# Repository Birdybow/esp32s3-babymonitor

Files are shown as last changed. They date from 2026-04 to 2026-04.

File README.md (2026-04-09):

# ESP32-S3 BabyMonitor

A self-hosted baby monitor built on the **Freenove ESP32-S3 WROOM (N16R8)** with full two-way communication — live video, live audio, and push-to-talk — all accessible from a web browser or Home Assistant dashboard.

No cloud. No app. No subscription.

---

## Features

- **Live video** — MJPEG stream over HTTP (port 80), compatible with go2rtc and Home Assistant
- **Live audio** — continuous WAV stream from INMP441 microphone (port 81)
- **Push-to-talk** — hold a button in the browser to speak through the MAX98357A speaker (port 82)
- **mDNS** — access via `http://babymonitor.local` without finding the IP address
- **Home Assistant integration** — embed video via go2rtc and the audio/talk player as dashboard cards

---

## Hardware

| Component | Part | Pins |
|---|---|---|
| Microcontroller | Freenove ESP32-S3 WROOM N16R8 | — |
| Camera | OV5640 (built-in) | XCLK=15, SIOD=4, SIOC=5, VSYNC=6, HREF=7, PCLK=13, Y2–Y9=11,9,8,10,12,18,17,16 |
| Microphone | INMP441 (I2S) | SCK=GPIO3, WS=GPIO21, SD=GPIO1 |
| Speaker amplifier | MAX98357A (I2S) | BCLK=GPIO41, LRC=GPIO42, DOUT=GPIO47 |

> **Note:** GPIO14 is defective (stuck HIGH) on the tested board. GPIO3 is used for I2S SCK instead — it is a strapping pin but works reliably as I2S clock after boot.

---

## Wiring

```
INMP441 microphone:
  VDD  → 3.3V
  GND  → GND
  SCK  → GPIO3
  WS   → GPIO21
  SD   → GPIO1
  L/R  → GND  (selects left channel)

MAX98357A speaker amplifier:
  VIN  → 5V
  GND  → GND
  BCLK → GPIO41
  LRC  → GPIO42
  DIN  → GPIO47
```

---

## HTTP Endpoints

| Port | Path | Description |
|---|---|---|
| 80 | `/` | Status page with links |
| 80 | `/stream` | MJPEG live video stream |
| 80 | `/capture` | Single JPEG snapshot |
| 81 | `/audio` | WAV audio stream (16kHz, 16-bit mono) |
| 82 | `/player` | Browser UI — listen + push-to-talk |
| 82 | `/speak` | POST endpoint — receives PCM audio, plays on speaker |

---

## Arduino IDE Setup

1. Install **ESP32 board support** (Espressif) in Arduino IDE
2. Select board: `ESP32S3 Dev Module`
3. Settings:
   - Flash: `16MB (128Mb)`
   - Partition Scheme: `Huge APP (3MB No OTA / 1MB SPIFFS)`
   - PSRAM: `OPI PSRAM`
   - USB CDC On Boot: `Disabled`
4. Open `firmware/BabyMonitor.ino`
5. Edit WiFi credentials at the top of the file:
   ```cpp
   static const char* WIFI_SSID = "DITT_WIFI_NAVN";
   static const char* WIFI_PASS = "DITT_WIFI_PASSORD";
   ```
6. Flash via the right USB-C port (CH343 UART)

---

## Browser – Push-to-Talk (getUserMedia over HTTP)

Chrome blocks microphone access on non-HTTPS origins by default. To allow it on your local network:

1. Open: `chrome://flags/#unsafely-treat-insecure-origin-as-secure`
2. Add: `http://babymonitor.local:82`
3. Click **Enable** → **Relaunch**
4. Go to `http://babymonitor.local:82/player`
5. Hold the blue button to speak

---

## Home Assistant Integration

### go2rtc (video)

Add to `/config/go2rtc.yaml`:
```yaml
streams:
  babymonitor_video:
    - ffmpeg:http://babymonitor.local/stream#video=mjpeg
```

### Dashboard cards

**Video card** (Webpage card):
```
http://<your-ha-ip>:11984/stream.html?src=babymonitor_video&mode=mjpeg
```

**Audio/talk card** (Webpage card):
```
http://babymonitor.local:82/player
```

---

## 3D Printed Enclosure

The `hardware/` folder contains a `.3mf` file (Bambu Lab format) for a wall-mounted enclosure designed around the SG90 servo pan mechanism.

**Design concept:** The SG90 servo is fixed to the wall. The bowl-shaped enclosure (containing the ESP32-S3, microphone, and speaker) rotates around the servo horn, giving 180° horizontal pan.

**Print settings used:**
| Setting | Value |
|---|---|
| Printer | Bambu Lab |
| Filament | PLA |
| Layer height | 0.2 mm |
| Infill | 15% |
| Supports | No |

**Assembly notes:**
- Glue the SG90 plastic horn wings to the bottom of the bowl
- Mount the servo body to the wall — the enclosure rotates around it
- Route cables (USB-C power, speaker wires) with enough slack for full 180° rotation
- SG90 requires a **separate 5V power supply** — the ESP32-S3 board's 5V pin only delivers ~4.1V which is insufficient

> The `.3mf` file opens in Bambu Studio and most modern slicers (PrusaSlicer, OrcaSlicer).

---

## Architecture

Three separate HTTP servers are required because `esp_http_server` is single-threaded. The MJPEG stream handler on port 80 holds the connection permanently — if `/player` were also on port 80, it would never receive a response.

```
Port 80  — video_server  — /stream (blocking MJPEG), /capture, /
Port 81  — audio_server  — /audio  (blocking WAV stream)
Port 82  — speak_server  — /player (HTML UI), /speak (POST PCM → speaker)
```

```mermaid
flowchart LR
    subgraph ESP32-S3
        CAM[OV5640\nCamera]
        MIC[INMP441\nMicrophone]
        SPK[MAX98357A\nSpeaker]
        P80[Port 80\nvideo_server]
        P81[Port 81\naudio_server]
        P82[Port 82\nspeak_server]
        CAM --> P80
        MIC --> P81
        P82 --> SPK
    end

    subgraph Home Assistant
        go2rtc[go2rtc]
        dash[Dashboard]
        P80 -->|MJPEG| go2rtc
        go2rtc -->|iframe| dash
    end

    subgraph Browser
        vid[Video card]
        player[Audio/PTT player]
        go2rtc --> vid
        P81 -->|WAV stream| player
        player -->|POST PCM| P82
        P82 -->|HTML UI| player
    end
```

---

## Latency

| Stream | Typical delay |
|---|---|
| Video (MJPEG via go2rtc) | 1–3 seconds |
| Audio (WAV stream in browser) | ~0.5 seconds |
| Push-to-talk (browser → speaker) | ~0.3 seconds |

MJPEG latency is dominated by go2rtc buffering. Direct MJPEG (`http://babymonitor.local/stream`) is faster but not embeddable in HA dashboards without go2rtc.

---

## Known Limitations

This is a hobby and educational project. Be aware of the following before deploying it:

- **No encryption** — all streams are plain HTTP on the local network
- **No authentication** — anyone on the same WiFi can access the video, audio, and speaker
- **MJPEG is bandwidth-heavy** — not suitable for remote access over mobile data
- **No acoustic echo cancellation (AEC)** — you will hear yourself if audio is playing while you push to talk
- **Not a certified product** — not suitable as a sole safety device for infants

---

## Tested With

| Component | Version |
|---|---|
| Home Assistant OS | 2026.4.0 |
| go2rtc (built into HA) | 1.9.x |
| Arduino IDE | 2.x |
| ESP32 Arduino core | 3.x |
| Chrome | 134+ |

---

## Background

This project was developed as part of a Home Assistant and IoT course at a Norwegian vocational college. It is shared openly because there is very little documentation on combining real-time audio streaming, push-to-talk, and MJPEG video on a single ESP32-S3 using only the Arduino framework and standard HTTP servers.

If you find it useful or build on it — great!

---

## Credits

Built by **Bård Kjellhov-Reinton**, teacher at Fagskolen i Viken avd. Kongsberg, as part of a Home Assistant and IoT course. Developed together with Claude (Anthropic) through an iterative process of building, hitting walls, and figuring it out.

## License

MIT

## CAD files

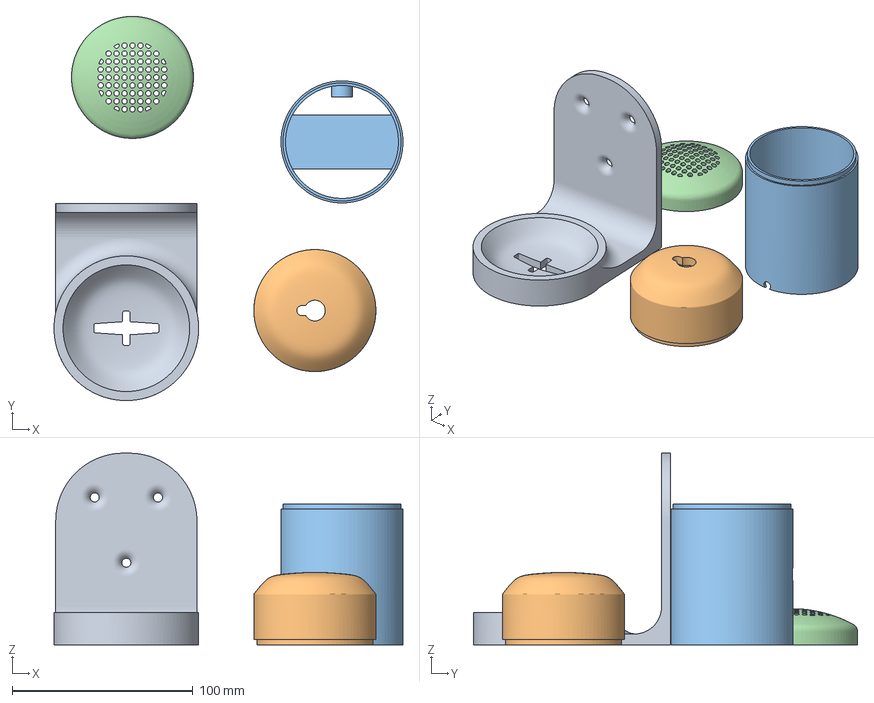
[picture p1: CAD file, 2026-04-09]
hardware/Kameramount_Babymonitor_v1.3mf
193.0 x 212.4 x 106.0 mm

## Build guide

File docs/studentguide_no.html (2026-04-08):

# BabyMonitor med ESP32-S3

Live video, live lyd og push-to-talk – ingen sky, ingen app, ingen abonnement

🔗 GitHub-repository (åpen kildekode) (https://github.com/Birdybow/esp32s3-babymonitor)

### Innholdsfortegnelse

1. Hva du skal bygge
2. Utstyrsliste og kobling
3. Arduino IDE – oppsett og flash
4. Test at det virker
5. Chrome-flagg for push-to-talk
6. Home Assistant-integrasjon
7. Forstå det du bygde
8. Hva ville vi gjort annerledes?

## 1 Hva du skal bygge

I denne oppgaven bygger du en selvdriftet babymonitor med to-veis kommunikasjon. Alt kjører på ditt lokale nettverk – ingenting sendes til skyen.

Funksjon | Teknologi | Tilgang
Live video | MJPEG over HTTP | http://babymonitor.local/stream
Live lyd (lytte) | WAV-strøm over HTTP | http://babymonitor.local:81/audio
Push-to-talk (snakke) | Web Audio API → HTTP POST → I2S | http://babymonitor.local:82/player

Port 80 → Video (MJPEG-strøm) → go2rtc → HA-dashboard
Port 81 → Lyd ut (WAV-strøm) → nettleser
Port 82 → Lyd inn (PCM POST) ← nettleser → høyttaler

Læringsmål: Etter denne oppgaven forstår du HTTP-streaming, I2S-lyd, Web Audio API, mDNS, og hvorfor nettlesere krever HTTPS for mikrofontilgang.

## 2 Utstyrsliste og kobling

### Komponenter

Komponent | Antall | Merknad
Freenove ESP32-S3 WROOM N16R8 | 1 | Har innebygd OV5640-kamera og OPI PSRAM
INMP441 I2S-mikrofon | 1 | Digital MEMS-mikrofon, 3.3V
MAX98357A I2S-forsterker | 1 | Klasse D, 3W, 3.3–5V, mono
Liten høyttaler (4–8 Ω) | 1 | Kobles til MAX98357A
Breadboard og ledninger | – | Hann-hunn og hann-hann
USB-C kabel | 1 | Til flashing (høyre USB-C på brettet)

### Kobling – INMP441 mikrofon

INMP441-pin | ESP32-S3 GPIO | Merknad
VDD | 3.3V | Maks 3.6V – aldri 5V!
GND | GND
SCK | GPIO3 | I2S klokke (BCK)
WS | GPIO21 | Word Select (venstre/høyre)
SD | GPIO1 | Seriedata ut fra mikrofon
L/R | GND | Velger venstre kanal

### Kobling – MAX98357A høyttaler

MAX98357A-pin | ESP32-S3 GPIO | Merknad
VIN | 5V | Fra USB-pin på brettet
GND | GND
BCLK | GPIO41 | I2S bit-klokke
LRC | GPIO42 | Left/Right klokke (WS)
DIN | GPIO47 | Seriedata inn til forsterker
SD | – | La stå ukoblet (aktivert som standard)

Advarsel: INMP441 tåler maksimalt 3.6V. Bruk alltid 3.3V-pinnen på ESP32-S3, aldri 5V.

## 3 Arduino IDE – oppsett og flash

### Arduino IDE-innstillinger

Åpne Arduino IDE → Tools → Board → ESP32 Arduino → ESP32S3 Dev Module

Sett Flash Size til 16MB (128Mb)

Sett Partition Scheme til Huge APP (3MB No OTA / 1MB SPIFFS)

Sett PSRAM til OPI PSRAM

Sett USB CDC On Boot til Disabled

### Hent koden

Last ned koden fra github.com/Birdybow/esp32s3-babymonitor (klikk Code → Download ZIP)

Pakk ut og åpne firmware/BabyMonitor.ino i Arduino IDE

### Endre WiFi-innstillinger

Øverst i filen finner du disse to linjene. Endre dem til ditt nettverk:

📄 BabyMonitor.ino – WiFi-konfigurasjon

static const char* WIFI_SSID     = "DITT_WIFI_NAVN";     // ← endre her
static const char* WIFI_PASS     = "DITT_WIFI_PASSORD";  // ← endre her
static const char* MDNS_HOSTNAME = "babymonitor";        // http://babymonitor.local

### Flash til brettet

Koble USB-C-kabelen til høyre USB-C-port på Freenove-brettet (CH343 UART-chip)

Velg riktig COM-port under Tools → Port

Trykk Upload (pil-knappen). Hold BOOT-knappen på brettet nede hvis opplastingen ikke starter automatisk.

Riktig USB-port er viktig! Freenove ESP32-S3 har to USB-C-porter. Venstre er native USB (brukes til ESP-IDF), høyre er CH343 UART og brukes til Arduino. Bruk alltid høyre port.

## 4 Test at det virker

### Sjekk seriellmonitor

Åpne Tools → Serial Monitor (115200 baud). Du skal se noe slikt:

╔══════════════════════════╗ ║ BabyMonitor ║ ╚══════════════════════════╝ [KAMERA] OK – VGA JPEG [MIC] OK – INMP441 16kHz I2S [SPK] OK – MAX98357A 16kHz I2S [WIFI] OK – IP: 192.168.x.x [mDNS] http://babymonitor.local [HTTP] Video-server startet på port 80 [HTTP] Lyd-server startet på port 81 [HTTP] Tale-server startet på port 82 ─── Klar ─────────────────────────── Video: http://192.168.x.x/stream Spiller: http://192.168.x.x:82/player Lyd inn: http://192.168.x.x:81/audio Tale ut: http://192.168.x.x:82/speak

### Test i nettleser

Åpne http://babymonitor.local/stream – du skal se live video

Åpne http://babymonitor.local:82/player – du skal se lydspeilleren

Trykk Lytt live – du skal høre lyd fra mikrofonen

Fungerer video og lyd? Da er fase 1 og 2 fullført. Push-to-talk krever ett ekstra steg i Chrome – se neste avsnitt.

## 5 Chrome-flagg for push-to-talk

Chrome blokkerer mikrofontilgang (getUserMedia) på sider som ikke bruker HTTPS. Siden babymonitoren kjører på lokalt nettverk uten sertifikat, må vi eksplisitt godkjenne adressen.

Åpne Chrome og gå til: chrome://flags/#unsafely-treat-insecure-origin-as-secure

Lim inn http://babymonitor.local:82 i feltet og klikk Enable

Klikk Relaunch (Chrome starter på nytt)

Gå til http://babymonitor.local:82/player

Hold den blå mikrofonknappen nede og snakk – du skal høre deg selv i høyttaleren

Gratulerer! Du har nå full to-veis kommunikasjon: video, lyd og tale – alt over HTTP på lokalt nettverk.

Hvorfor krever Chrome HTTPS? Se avsnitt 7.5 for en grundig forklaring om «secure context» og hva det betyr for IoT-prosjekter.

## 6 Home Assistant-integrasjon

### Video via go2rtc

go2rtc er en strømmemotor innebygd i Home Assistant. Den henter MJPEG fra ESP32-en og gjør den tilgjengelig som en HA-strøm.

I HA: gå til Studio Code Server og åpne /config/go2rtc.yaml

Legg til:

📄 go2rtc.yaml

streams:
  babymonitor_video:
    - ffmpeg:http://babymonitor.local/stream#video=mjpeg

Start HA på nytt (eller kall go2rtc API via Developer Tools)

### Dashboard-kort

Legg til et Webpage-kort i dashboardet med URL:

📄 Video-kort URL

http://<HA-IP>:11984/stream.html?src=babymonitor_video&mode=mjpeg

Legg til enda et Webpage-kort for lyd og tale:

📄 Lyd/tale-kort URL

http://babymonitor.local:82/player

Merk: Chrome-flagget du satte i steg 5 gjelder også når HA-dashboardet vises i Chrome. Flagget trenger bare å settes én gang per nettleser.

## 7 Forstå det du bygde

Denne delen forklarer hvorfor systemet er bygget slik det er. Alle valgene ble tatt av en grunn – og i hvert tilfelle er det en generell lærdom som du kan ta med deg til andre prosjekter.

### 7.1 – Hvorfor tre HTTP-servere?

Bibliotekbegrensning

#### esp_http_server er entrådet

esp_http_server – det innebygde HTTP-biblioteket i ESP32 Arduino-rammeverket – har én enkelt tråd per serverinstans. Når en handler starter, blokkerer den alle andre forespørsler til den er ferdig.

MJPEG-strømmingen (video) og WAV-strømmingen (lyd) er aldri ferdige – de holder tilkoblingen åpen så lenge klienten er koblet til. Hvis vi hadde lagt alle endepunkter på samme server, ville aldri /player fått svar.

Løsningen: Tre separate serverinstanser på port 80, 81 og 82. Hver har sin egen tråd og kan ta imot forespørsler uavhengig.

Generell lærdom: Når et bibliotek setter deg i en krok, studer begrensningen og design rundt den – ikke mot den.

### 7.2 – Hvorfor sende WAV og ikke rå PCM?

Elegant design

#### Endre data slik at verktøyet ikke trenger konfigurasjon

go2rtc bruker ffmpeg til å lese lydkilder. ffmpeg kan lese rå PCM, men da må du spesifisere format eksplisitt i kilde-URL-en:

-f s16le -ar 16000 -ac 1 -i http://babymonitor.local:81/audio

Problemet er at go2rtc sin API ikke alltid aksepterer mellomrom i kilde-strenger. Løsningen var å sende en WAV-header først – da gjenkjenner ffmpeg formatet automatisk og ingen argumenter trengs:

ffmpeg:http://babymonitor.local:81/audio

WAV-headeren er bare 44 bytes og inneholder all informasjon ffmpeg trenger: sample rate, bitdybde, antall kanaler.

Generell lærdom: Når du sliter mot et verktøy, spør deg: kan jeg endre dataene i stedet for konfigurasjonen? Det er ofte mer robust.

### 7.3 – Hvorfor push-to-talk og ikke full-duplex?

Produktbeslutning

#### Den enklere tekniske løsningen er ofte den bedre produktbeslutningen

Full-duplex lyd – der mikrofon og høyttaler er aktive samtidig – krever Acoustic Echo Cancellation (AEC). Uten AEC vil høyttaleren mate lyd tilbake til mikrofonen, og du hører ekko av deg selv i en evig løkke.

AEC på ESP32 er ekstremt krevende å implementere og ville tatt uker å finjustere. Push-to-talk løser problemet elegant: mikrofonen er aktiv kun mens du holder knappen, og høyttaleren er stille i mellomtiden.

Push-to-talk er også ærligere mot brukssituasjonen: du vil ha bevisst kontroll over når du snakker til et barn, ikke en åpen kanal som plukker opp alt som skjer i rommet.

Generell lærdom: Teknisk kompleksitet er ikke alltid et tegn på kvalitet. Spør alltid: hva er det faktiske behovet?

### 7.4 – Hvorfor stillhetsbuffere rundt avspillingen?

Profesjonell audioteknikk

#### DMA-buffere og transientlyder

I2S på ESP32 bruker DMA (Direct Memory Access) til å overføre lyd til høyttaleren. DMA-bufferne fylles kontinuerlig – og hvis det siste som lå i bufferen var lydata, og neste oppdatering plutselig er null, oppstår det en brå overgang som høres som et klikk eller pop.

Løsningen er å sende noen frames med stille lyd (0) like før og etter avspillingen. Det gir DMA-bufferne tid til å «lande» mykt.

int16_t silence[64] = {0};
i2s_write(I2S_NUM_1, silence, sizeof(silence), &written, portMAX_DELAY);
// ... avspilling ...
i2s_write(I2S_NUM_1, silence, sizeof(silence), &written, portMAX_DELAY);

Generell lærdom: Dette er standardteknikken i profesjonelle audiopipelines – fra studio-DAW-er til Bluetooth-høyttalere. Det er ingen hack; det er slik det gjøres.

### 7.5 – Hvorfor krever Chrome HTTPS for mikrofontilgang?

Websikkerhet

#### Secure context og sensitive API-er

Nettlesere skiller mellom secure contexts (HTTPS eller localhost) og usikre (HTTP). Siden 2017 krever en rekke sensitive nettleser-API-er secure context:

- navigator.mediaDevices.getUserMedia() – mikrofon og kamera
- navigator.geolocation – posisjon
- Service Workers, Web Bluetooth, Web USB

Begrunnelsen er reell: hvis en angriper kan avlytte HTTP-trafikk (man-in-the-middle), kan de injisere kode som stjeler mikrofon- eller kameraopptak. HTTPS forhindrer dette.

#### For IoT på lokalnett – tre tilnærminger

Tilnærming | Ulempe
Chrome-flagg (det vi brukte) | Må gjøres per nettleser, kun for utvikling/kontrollerte miljøer
Selvsignert sertifikat (self-signed cert) | Nettleseren viser advarsel, må godkjennes manuelt
Let's Encrypt via reverse proxy (f.eks. Nginx) | Krever domenenavn og port-forwarding – mer komplekst

Generell lærdom: Webplattformens sikkerhetsmodell er designet for offentlig internett og kolliderer ofte med embedded-virkeligheten. Forstå hvorfor regelen finnes – da vet du også når det er OK å omgå den.

## 8 Hva ville vi gjort annerledes?

En god ingeniør evaluerer sitt eget arbeid kritisk. Her er en ærlig gjennomgang av hva som kunne vært bedre i dette prosjektet:

### Autentisering

Alle HTTP-endepunktene er åpne for alle på nettverket. Hvem som helst på samme WiFi kan lytte på lydstrømmen eller sende lyd til høyttaleren. For et reelt produkt ville vi lagt til enkel HTTP Basic Auth eller et token-basert system.

### OTA-oppdateringer (Over The Air)

Vi valgte partisjonsoppsettet «Huge APP» for å få plass til kamera- og lydbibliotekene. Det betyr at OTA-oppdatering ikke er mulig. En fremtidig versjon burde bruke en mindre kjernebibliotek-kombinasjon og aktivere OTA, slik at brettet kan oppdateres uten å koble til USB-kabel.

### H.264 video i stedet for MJPEG

MJPEG sender hvert bilde som en komprimert JPEG. H.264 er langt mer effektivt (sender bare endringer mellom bilder), men krever hardware-enkoding som ikke er støttet i go2rtc sin standard HA-bygg. MJPEG er enkelt og pålitelig – men bruker mer båndbredde.

### mDNS-avhengighet

Hele systemet er koblet opp mot babymonitor.local via mDNS. mDNS er ikke alltid pålitelig på tvers av subnett eller på noen WiFi-routere. I produksjon ville vi reservert en fast IP-adresse via DHCP-reservasjon i routeren, og brukt den som backup.

### Ingen rekobling ved WiFi-tap

Hvis WiFi-forbindelsen mistes, kobler ikke brettet seg til igjen automatisk uten omstart. En robust løsning ville overvåket tilkoblingsstatus i loop() og kalt WiFi.reconnect() ved behov.

Poenget: Alle disse forbeholdene er bevisste avveiinger mellom kompleksitet og nytte for et undervisnings- og hobbyprosjekt. Et ferdig produkt ville løst dem. Å vite hva man ikke har løst er like viktig som å vite hva man har løst.

## Ressurser og videre lesning

- GitHub-repository med kildekode og README (https://github.com/Birdybow/esp32s3-babymonitor)
- Espressif – I2S-driver dokumentasjon (https://docs.espressif.com/projects/esp-idf/en/latest/esp32s3/api-reference/peripherals/i2s.html)
- MDN – Web Audio API (https://developer.mozilla.org/en-US/docs/Web/API/Web_Audio_API)
- MDN – Secure Contexts (HTTPS og getUserMedia) (https://developer.mozilla.org/en-US/docs/Web/Security/Secure_Contexts)
- Home Assistant – go2rtc integrasjon (https://www.home-assistant.io/integrations/go2rtc/)

Laget av Bård Kjellhov-Reinton – Fagskolen i Viken avd. Kongsberg | Utviklet i samarbeid med Claude (Anthropic) | Åpen kildekode på GitHub (https://github.com/Birdybow/esp32s3-babymonitor)

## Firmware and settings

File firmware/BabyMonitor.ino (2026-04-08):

/**
 * BabyMonitor – Freenove ESP32-S3 WROOM (N16R8)
 * ================================================
 * Video:  OV5640  → HTTP MJPEG  på port 80,  GET /stream
 * Lyd:    INMP441 → HTTP PCM   på port 81,  GET /audio
 * Servo:  SG90   ← HTTP GET   på port 82,  GET /servo?angle=0..180
 *
 * go2rtc-konfig i HA (/config/go2rtc.yaml):
 * ------------------------------------------
 *   streams:
 *     babymonitor:
 *       - ffmpeg:http://babymonitor.local/stream#video=mjpeg
 *       - ffmpeg:-f s16le -ar 16000 -ac 1 -i http://babymonitor.local:81/audio#audio=pcm
 *
 * Arduino IDE-innstillinger:
 * ---------------------------
 *   Board:              ESP32S3 Dev Module
 *   Flash:              16MB (128Mb)
 *   Partition Scheme:   Huge APP (3MB No OTA/1MB SPIFFS)
 *   PSRAM:              OPI PSRAM
 *   USB CDC On Boot:    Disabled
 *   Port:               UART-porten (høyre USB-C – "USB-Enhanced-SERIAL CH343", COM5)
 *
 * Første flash: USB-kabel til venstre USB-C (CH343).
 * Hold BOOT-knappen nede ved oppstart hvis nødvendig.
 */

#include "esp_camera.h"
#include "esp_http_server.h"
#include <WiFi.h>
#include <ESPmDNS.h>
#include <driver/i2s.h>
#include <driver/gpio.h>

// ─── WiFi / nettverksnavn ─────────────────────────────────────────────────────
static const char* WIFI_SSID     = "ved rutern";
static const char* WIFI_PASS     = "Banankasse123";
static const char* MDNS_HOSTNAME = "babymonitor";        // http://babymonitor.local

// ─── Kamera-pins (Freenove ESP32-S3 EYE – OV5640) ────────────────────────────
#define CAM_PWDN   -1
#define CAM_RESET  -1
#define CAM_XCLK   15
#define CAM_SIOD    4
#define CAM_SIOC    5
#define CAM_Y9     16
#define CAM_Y8     17
#define CAM_Y7     18
#define CAM_Y6     12
#define CAM_Y5     10
#define CAM_Y4      8
#define CAM_Y3      9
#define CAM_Y2     11
#define CAM_VSYNC   6
#define CAM_HREF    7
#define CAM_PCLK   13

// ─── Mikrofon-pins (INMP441 – I2S standard) ───────────────────────────────────
// Merk: GPIO14 er defekt (stuck HIGH) på dette brettet – bruk GPIO3 for SCK.
// GPIO3 er strapping-pin, men fungerer fint som I2S SCK etter boot.
#define MIC_SCK   3
#define MIC_WS   21
#define MIC_SD    1

// ─── Høyttaler-pins (MAX98357A – I2S standard) ───────────────────────────────
#define SPK_BCLK  41
#define SPK_LRC   42
#define SPK_DOUT  47

// ─── Servo-pins og konfigurasjon (SG90) ───────────────────────────────────────
#define SERVO_PIN      2    // GPIO2 – ledig, PWM-kapabel
#define SERVO_FREQ    50    // 50 Hz – standard for RC-servoer
#define SERVO_RES     16    // 16-bit oppløsning (0–65535)
// SG90 pulsebredde: 0.5 ms (0°) → 2.4 ms (180°) ved 20 ms periode
// 13-bit oppløsning (8192 counts): 0.5/20×8192=205, 2.4/20×8192=983
#define SERVO_MIN_DUTY  205   // 0.5 ms
#define SERVO_MAX_DUTY  983   // 2.4 ms

static int servo_angle = 90;   // startposisjon: midten

// ─── Lydkonfigurasjon ─────────────────────────────────────────────────────────
#define AUDIO_SAMPLE_RATE  16000   // Hz – godt nok for stemmer og gråt
#define AUDIO_BUF_SAMPLES   256   // Samples per I2S-lesning (256 × 4B = 1 kB)
#define SPEAK_BUF_SAMPLES   512   // Samples per I2S-skriving til høyttaler

// Skiftverdi for konvertering fra INMP441 32-bit til 16-bit.
// INMP441 sender 24-bit verdi left-justified i 32-bit ord.
// >> 11 gir god amplitude for tale. Reduser (f.eks. >> 8) hvis lyden er for svak.
#define MIC_GAIN_SHIFT  11

// =============================================================================
// SERVO
// =============================================================================

static void servo_set_angle(int angle) {
  angle = max(0, min(180, angle));
  servo_angle = angle;
  uint32_t duty = SERVO_MIN_DUTY + (uint32_t)((float)angle / 180.0f * (SERVO_MAX_DUTY - SERVO_MIN_DUTY));
  ledcWrite(SERVO_PIN, duty);
}

static bool servo_init() {
  // ledcAttachChannel: eksplisitt kanal 2 for å unngå konflikt med kameraets LEDC kanal 0
  ledcAttachChannel(SERVO_PIN, SERVO_FREQ, 13, 2);
  ledcWrite(SERVO_PIN, 0);   // ingen puls ved oppstart – unngår brownout
  Serial.println("[SERVO] OK – SG90 GPIO2, 13-bit PWM, klar");
  return true;
}

// ─── HTTP-serverinstanser ─────────────────────────────────────────────────────
// Tre separate servere – esp_http_server er entrådet, strømmende handlers
// blokkerer andre forespørsler på samme server.
static httpd_handle_t video_server = NULL;   // port 80: /, /stream, /capture, /player
static httpd_handle_t audio_server = NULL;   // port 81: /audio (inn fra mikrofon)
static httpd_handle_t speak_server = NULL;   // port 82: /speak  (ut til høyttaler)

// =============================================================================
// KAMERA
// =============================================================================

static bool kamera_init() {
  camera_config_t cfg = {};
  cfg.ledc_channel  = LEDC_CHANNEL_0;
  cfg.ledc_timer    = LEDC_TIMER_0;
  cfg.pin_d0        = CAM_Y2;
  cfg.pin_d1        = CAM_Y3;
  cfg.pin_d2        = CAM_Y4;
  cfg.pin_d3        = CAM_Y5;
  cfg.pin_d4        = CAM_Y6;
  cfg.pin_d5        = CAM_Y7;
  cfg.pin_d6        = CAM_Y8;
  cfg.pin_d7        = CAM_Y9;
  cfg.pin_xclk      = CAM_XCLK;
  cfg.pin_pclk      = CAM_PCLK;
  cfg.pin_vsync     = CAM_VSYNC;
  cfg.pin_href      = CAM_HREF;
  cfg.pin_sscb_sda  = CAM_SIOD;
  cfg.pin_sscb_scl  = CAM_SIOC;
  cfg.pin_pwdn      = CAM_PWDN;
  cfg.pin_reset     = CAM_RESET;
  cfg.xclk_freq_hz  = 20000000;
  cfg.pixel_format  = PIXFORMAT_JPEG;
  cfg.frame_size    = FRAMESIZE_VGA;      // 640×480 – god balanse kvalitet/båndbredde
  cfg.jpeg_quality  = 12;                 // 0 = best, 63 = dårligst
  cfg.fb_count      = 2;                  // dobbel-buffering i PSRAM
  cfg.grab_mode     = CAMERA_GRAB_LATEST; // alltid ferskest bilde
  cfg.fb_location   = CAMERA_FB_IN_PSRAM;

  esp_err_t err = esp_camera_init(&cfg);
  if (err != ESP_OK) {
    Serial.printf("[KAMERA] Init feilet: 0x%x\n", err);
    return false;
  }

  sensor_t *s = esp_camera_sensor_get();
  s->set_vflip(s, 1);     // kameraet er montert opp-ned
  s->set_hmirror(s, 1);
  s->set_brightness(s, 1);

  Serial.println("[KAMERA] OK – VGA JPEG");
  return true;
}

// =============================================================================
// MIKROFON
// =============================================================================

static bool mikrofon_init() {
  // Frigjør GPIO1 fra evt. ADC/touch-funksjon
  gpio_reset_pin(GPIO_NUM_1);
  gpio_set_direction(GPIO_NUM_1, GPIO_MODE_INPUT);

  i2s_config_t cfg = {
    .mode                 = (i2s_mode_t)(I2S_MODE_MASTER | I2S_MODE_RX),
    .sample_rate          = AUDIO_SAMPLE_RATE,
    .bits_per_sample      = I2S_BITS_PER_SAMPLE_32BIT,  // INMP441 sender 24-bit i 32-bit ord
    .channel_format       = I2S_CHANNEL_FMT_ONLY_LEFT,  // INMP441 L/R-pin koblet til GND = venstre kanal
    .communication_format = I2S_COMM_FORMAT_STAND_I2S,
    .intr_alloc_flags     = ESP_INTR_FLAG_LEVEL1,
    .dma_buf_count        = 8,
    .dma_buf_len          = AUDIO_BUF_SAMPLES,
    .use_apll             = false,
  };

  i2s_pin_config_t pins = {
    .mck_io_num   = I2S_PIN_NO_CHANGE,
    .bck_io_num   = MIC_SCK,
    .ws_io_num    = MIC_WS,
    .data_out_num = I2S_PIN_NO_CHANGE,
    .data_in_num  = MIC_SD,
  };

  esp_err_t err = i2s_driver_install(I2S_NUM_0, &cfg, 0, NULL);
  if (err != ESP_OK) { Serial.printf("[MIC] i2s_driver_install feilet: 0x%x\n", err); return false; }

  err = i2s_set_pin(I2S_NUM_0, &pins);
  if (err != ESP_OK) { Serial.printf("[MIC] i2s_set_pin feilet: 0x%x\n", err); return false; }

  Serial.println("[MIC] OK – INMP441 16kHz I2S");
  return true;
}

// =============================================================================
// HØYTTALER
// =============================================================================

static bool hoyttaler_init() {
  i2s_config_t cfg = {
    .mode                 = (i2s_mode_t)(I2S_MODE_MASTER | I2S_MODE_TX),
    .sample_rate          = AUDIO_SAMPLE_RATE,
    .bits_per_sample      = I2S_BITS_PER_SAMPLE_16BIT,
    .channel_format       = I2S_CHANNEL_FMT_ONLY_LEFT,
    .communication_format = I2S_COMM_FORMAT_STAND_I2S,
    .intr_alloc_flags     = ESP_INTR_FLAG_LEVEL1,
    .dma_buf_count        = 8,
    .dma_buf_len          = SPEAK_BUF_SAMPLES,
    .use_apll             = false,
  };

  i2s_pin_config_t pins = {
    .mck_io_num   = I2S_PIN_NO_CHANGE,
    .bck_io_num   = SPK_BCLK,
    .ws_io_num    = SPK_LRC,
    .data_out_num = SPK_DOUT,
    .data_in_num  = I2S_PIN_NO_CHANGE,
  };

  esp_err_t err = i2s_driver_install(I2S_NUM_1, &cfg, 0, NULL);
  if (err != ESP_OK) { Serial.printf("[SPK] install feilet: 0x%x\n", err); return false; }

  err = i2s_set_pin(I2S_NUM_1, &pins);
  if (err != ESP_OK) { Serial.printf("[SPK] pin feilet: 0x%x\n", err); return false; }

  // Send stilhet for å tømme DMA-buffer og unngå pop ved første avspilling
  int16_t silence[SPEAK_BUF_SAMPLES] = {0};
  size_t written;
  i2s_write(I2S_NUM_1, silence, sizeof(silence), &written, 100);

  Serial.println("[SPK] OK – MAX98357A 16kHz I2S");
  return true;
}

// =============================================================================
// HTTP-HANDLERE
// =============================================================================

// ── /stream – MJPEG multipart ─────────────────────────────────────────────────
#define MJPEG_BOUNDARY     "mjpegboundary"
#define MJPEG_CONTENT_TYPE "multipart/x-mixed-replace;boundary=" MJPEG_BOUNDARY
#define MJPEG_BOUNDARY_HDR "\r\n--" MJPEG_BOUNDARY "\r\n"
#define MJPEG_PART_HDR     "Content-Type: image/jpeg\r\nContent-Length: %u\r\n\r\n"

static esp_err_t stream_handler(httpd_req_t *req) {
  httpd_resp_set_type(req, MJPEG_CONTENT_TYPE);
  httpd_resp_set_hdr(req, "Access-Control-Allow-Origin", "*");
  httpd_resp_set_hdr(req, "Cache-Control", "no-cache");

  char part_hdr[64];
  Serial.println("[STREAM] Klient tilkoblet");

  while (true) {
    camera_fb_t *fb = esp_camera_fb_get();
    if (!fb) {
      Serial.println("[STREAM] Feil: ingen kamera-frame");
      return ESP_FAIL;
    }

    esp_err_t res = httpd_resp_send_chunk(req, MJPEG_BOUNDARY_HDR, strlen(MJPEG_BOUNDARY_HDR));

    if (res == ESP_OK) {
      size_t hlen = snprintf(part_hdr, sizeof(part_hdr), MJPEG_PART_HDR, fb->len);
      res = httpd_resp_send_chunk(req, part_hdr, hlen);
    }

    if (res == ESP_OK) {
      res = httpd_resp_send_chunk(req, (const char*)fb->buf, fb->len);
    }

    esp_camera_fb_return(fb);

    if (res != ESP_OK) {
      Serial.println("[STREAM] Klient koblet fra");
      break;
    }
  }

  return ESP_OK;
}

// ── /capture – enkeltbilde JPEG (brukes av HA Generic Camera som stillbilde-URL) ──
static esp_err_t capture_handler(httpd_req_t *req) {
  camera_fb_t *fb = esp_camera_fb_get();
  if (!fb) {
    httpd_resp_send_500(req);
    return ESP_FAIL;
  }
  httpd_resp_set_type(req, "image/jpeg");
  httpd_resp_set_hdr(req, "Access-Control-Allow-Origin", "*");
  httpd_resp_set_hdr(req, "Cache-Control", "no-cache");
  esp_err_t res = httpd_resp_send(req, (const char*)fb->buf, fb->len);
  esp_camera_fb_return(fb);
  return res;
}

// ── / – enkel statusside ──────────────────────────────────────────────────────
static esp_err_t index_handler(httpd_req_t *req) {
  char html[512];
  snprintf(html, sizeof(html),
    "<html><body style='font-family:sans-serif;padding:24px;max-width:400px'>"
    "<h2>BabyMonitor</h2>"
    "<p><a href='/stream'>Video (MJPEG)</a></p>"
    "<p><a href='/player'>Lydspiller</a></p>"
    "<p><a href='/capture'>Stillbilde</a></p>"
    "<hr><small>ESP32-S3 | OV5640 | INMP441</small>"
    "</body></html>");
  httpd_resp_set_type(req, "text/html");
  return httpd_resp_sendstr(req, html);
}

// ── /player – innebygd HTML-lydspiller (embed i HA-dashboard) ────────────────
// Bruker JavaScript for å opprette ny tilkobling ved hver play-hendelse,
// slik at lyden alltid er live og ikke fra buffer.
static esp_err_t player_handler(httpd_req_t *req) {
  const char* html =
    "<!DOCTYPE html><html>"
    "<head><meta charset='utf-8'>"
    "<style>"
    "  body{margin:0;background:#1a1a2e;display:flex;flex-direction:column;"
    "       align-items:center;justify-content:center;height:100vh;gap:14px;}"
    "  button{padding:12px 28px;font-size:15px;border:none;border-radius:8px;"
    "         cursor:pointer;font-family:sans-serif;transition:background 0.15s;}"
    "  #btnPlay{background:#4caf50;color:#fff;}"
    "  #btnStop{background:#e53935;color:#fff;}"
    "  #btnTale{background:#2196f3;color:#fff;width:160px;height:60px;"
    "           font-size:14px;border-radius:30px;user-select:none;}"
    "  .pan-row{display:flex;gap:10px;align-items:center;}"
    "  .pan-row button{padding:12px 18px;font-size:18px;background:#37474f;color:#fff;}"
    "  #lblAngle{color:#aaa;font-family:sans-serif;font-size:13px;min-width:50px;text-align:center;}"
    "  #status{color:#aaa;font-family:sans-serif;font-size:12px;text-align:center;}"
    "</style></head>"
    "<body>"
    "  <button id='btnPlay' onclick='startLyd()'>&#9654; Lytt live</button>"
    "  <button id='btnStop' onclick='stoppLyd()' disabled>&#9646;&#9646; Stopp</button>"
    "  <button id='btnTale'>&#127908; Hold for tale</button>"
    "  <div class='pan-row'>"
    "    <button onclick='pan(-15)'>&#9664;</button>"
    "    <span id='lblAngle'>90°</span>"
    "    <button onclick='pan(15)'>&#9654;</button>"
    "  </div>"
    "  <p id='status'>BabyMonitor – trykk for live lyd</p>"
    "<script>"
    // ── Lytte ──────────────────────────────────────────────────────────────
    "  var a=null;"
    "  function startLyd(){"
    "    stoppLyd();"
    "    a=new Audio('http://babymonitor.local:81/audio?t='+Date.now());"
    "    a.play();"
    "    st('Lytter live...');"
    "    document.getElementById('btnPlay').disabled=true;"
    "    document.getElementById('btnStop').disabled=false;"
    "  }"
    "  function stoppLyd(){"
    "    if(a){a.pause();a.src='';a.load();a=null;}"
    "    st('Stoppet');"
    "    document.getElementById('btnPlay').disabled=false;"
    "    document.getElementById('btnStop').disabled=true;"
    "  }"
    // ── Push-to-talk ────────────────────────────────────────────────────────
    "  var ctx,src,proc,strm,talking=false;"
    "  async function startTale(){"
    "    if(talking)return;"
    "    talking=true;"
    "    document.getElementById('btnTale').style.background='#ff9800';"
    "    try{"
    "      strm=await navigator.mediaDevices.getUserMedia({audio:true,video:false});"
    "      ctx=new AudioContext({sampleRate:16000});"
    "      src=ctx.createMediaStreamSource(strm);"
    "      proc=ctx.createScriptProcessor(2048,1,1);"
    "      src.connect(proc);proc.connect(ctx.destination);"
    "      proc.onaudioprocess=function(e){"
    "        if(!talking)return;"
    "        var f=e.inputBuffer.getChannelData(0);"
    "        var b=new Int16Array(f.length);"
    "        for(var i=0;i<f.length;i++){"
    "          var s=Math.max(-1,Math.min(1,f[i]));"
    "          b[i]=s<0?s*32768:s*32767;"
    "        }"
    "        fetch('http://babymonitor.local:82/speak',{"
    "          method:'POST',"
    "          headers:{'Content-Type':'application/octet-stream'},"
    "          body:b.buffer"
    "        }).catch(function(){});"
    "      };"
    "      st('Snakker...');"
    "    }catch(e){talking=false;st('Mikrofon: '+e.message);"
    "      document.getElementById('btnTale').style.background='#2196f3';}"
    "  }"
    "  function stoppTale(){"
    "    if(!talking)return;"
    "    talking=false;"
    "    if(proc){proc.disconnect();proc=null;}"
    "    if(src){src.disconnect();src=null;}"
    "    if(ctx){ctx.close();ctx=null;}"
    "    if(strm){strm.getTracks().forEach(function(t){t.stop()});strm=null;}"
    "    document.getElementById('btnTale').style.background='#2196f3';"
    "    st('Lytter live...');"
    "  }"
    "  var bt=document.getElementById('btnTale');"
    "  bt.addEventListener('mousedown',startTale);"
    "  bt.addEventListener('touchstart',function(e){e.preventDefault();startTale();});"
    "  bt.addEventListener('mouseup',stoppTale);"
    "  bt.addEventListener('mouseleave',stoppTale);"
    "  bt.addEventListener('touchend',stoppTale);"
    "  function st(t){document.getElementById('status').textContent=t;}"
    // ── Servo pan ───────────────────────────────────────────────────────────
    "  var panAngle=90;"
    "  function pan(delta){"
    "    panAngle=Math.max(0,Math.min(180,panAngle+delta));"
    "    document.getElementById('lblAngle').textContent=panAngle+'°';"
    "    fetch('/servo?angle='+panAngle).catch(function(){});"
    "  }"
    "</script>"
    "</body></html>";
  httpd_resp_set_type(req, "text/html");
  return httpd_resp_sendstr(req, html);
}

// ── /servo?angle=X – sett servovinkel (0–180) ────────────────────────────────
static esp_err_t servo_handler(httpd_req_t *req) {
  httpd_resp_set_hdr(req, "Access-Control-Allow-Origin", "*");

  char query[32] = {0};
  if (httpd_req_get_url_query_str(req, query, sizeof(query)) == ESP_OK) {
    char val[8] = {0};
    if (httpd_query_key_value(query, "angle", val, sizeof(val)) == ESP_OK) {
      int angle = atoi(val);
      servo_set_angle(angle);
      Serial.printf("[SERVO] Vinkel satt til %d°\n", servo_angle);
    }
  }

  char resp[32];
  snprintf(resp, sizeof(resp), "{\"angle\":%d}", servo_angle);
  httpd_resp_set_type(req, "application/json");
  return httpd_resp_sendstr(req, resp);
}

// ── /speak OPTIONS – CORS preflight (port 80→82 krever dette) ────────────────
static esp_err_t speak_options_handler(httpd_req_t *req) {
  httpd_resp_set_hdr(req, "Access-Control-Allow-Origin",  "*");
  httpd_resp_set_hdr(req, "Access-Control-Allow-Methods", "POST, OPTIONS");
  httpd_resp_set_hdr(req, "Access-Control-Allow-Headers", "Content-Type");
  httpd_resp_set_hdr(req, "Access-Control-Max-Age",       "86400");
  httpd_resp_set_status(req, "204 No Content");
  httpd_resp_send(req, NULL, 0);
  return ESP_OK;
}

// ── /speak POST – mottar int16 PCM fra nettleseren og spiller via høyttaler ──
static esp_err_t speak_handler(httpd_req_t *req) {
  httpd_resp_set_hdr(req, "Access-Control-Allow-Origin", "*");

  int total = req->content_len;
  if (total <= 0 || total > 65536) {
    httpd_resp_sendstr(req, "OK");
    return ESP_OK;
  }

  // Stilhet før for å unngå pop
  int16_t silence[64] = {0};
  size_t written;
  i2s_write(I2S_NUM_1, silence, sizeof(silence), &written, portMAX_DELAY);

  int16_t buf[SPEAK_BUF_SAMPLES];
  int received = 0;

  while (received < total) {
    int to_read = min((int)sizeof(buf), total - received);
    int ret = httpd_req_recv(req, (char*)buf, to_read);
    if (ret <= 0) break;
    i2s_write(I2S_NUM_1, buf, ret, &written, portMAX_DELAY);
    received += ret;
  }

  // Stilhet etter for å unngå pop
  memset(silence, 0, sizeof(silence));
  i2s_write(I2S_NUM_1, silence, sizeof(silence), &written, portMAX_DELAY);

  Serial.printf("[SPK] Spilte av %d bytes\n", received);
  httpd_resp_sendstr(req, "OK");
  return ESP_OK;
}

// ── /audio – chunked rå PCM (16kHz, 16-bit signed, mono, little-endian) ───────
// WAV-header for uendelig streaming (dataSize = 0xFFFFFFFF)
// ffmpeg auto-detekterer format – ingen mellomrom i go2rtc kilde-URL nødvendig
static void send_wav_header(httpd_req_t *req) {
  const uint32_t SAMPLE_RATE_HZ = AUDIO_SAMPLE_RATE;
  const uint16_t CHANNELS       = 1;
  const uint16_t BITS           = 16;
  const uint32_t BYTE_RATE      = SAMPLE_RATE_HZ * CHANNELS * BITS / 8;
  const uint16_t BLOCK_ALIGN    = CHANNELS * BITS / 8;

  uint8_t hdr[44] = {
    'R','I','F','F',
    0xFF,0xFF,0xFF,0xFF,        // fileSize – ukjent (uendelig strøm)
    'W','A','V','E',
    'f','m','t',' ',
    16,0,0,0,                   // fmtSize = 16
    1,0,                        // audioFormat = PCM
    (uint8_t)CHANNELS, 0,
    (uint8_t)(SAMPLE_RATE_HZ),  (uint8_t)(SAMPLE_RATE_HZ>>8),
    (uint8_t)(SAMPLE_RATE_HZ>>16),(uint8_t)(SAMPLE_RATE_HZ>>24),
    (uint8_t)(BYTE_RATE),       (uint8_t)(BYTE_RATE>>8),
    (uint8_t)(BYTE_RATE>>16),   (uint8_t)(BYTE_RATE>>24),
    (uint8_t)BLOCK_ALIGN, 0,
    BITS, 0,
    'd','a','t','a',
    0xFF,0xFF,0xFF,0xFF         // dataSize – ukjent (uendelig strøm)
  };
  httpd_resp_send_chunk(req, (const char*)hdr, sizeof(hdr));
}

static esp_err_t audio_handler(httpd_req_t *req) {
  httpd_resp_set_type(req, "audio/wav");
  httpd_resp_set_hdr(req, "Access-Control-Allow-Origin", "*");
  httpd_resp_set_hdr(req, "Cache-Control", "no-cache");

  // Send WAV-header først – ffmpeg og nettlesere gjenkjenner formatet automatisk
  send_wav_header(req);

  int32_t buf32[AUDIO_BUF_SAMPLES];
  int16_t buf16[AUDIO_BUF_SAMPLES];
  size_t  bytes_read;

  Serial.println("[AUDIO] Klient tilkoblet (WAV-stream)");

  while (true) {
    esp_err_t err = i2s_read(I2S_NUM_0, buf32, sizeof(buf32), &bytes_read, portMAX_DELAY);
    if (err != ESP_OK) {
      Serial.printf("[AUDIO] I2S read feilet: 0x%x\n", err);
      break;
    }

    int samples = bytes_read / sizeof(int32_t);
    for (int i = 0; i < samples; i++) {
      // INMP441: 24-bit data left-justified i 32-bit ord.
      // Shift ned for å få 16-bit PCM. Juster MIC_GAIN_SHIFT om lyden er for svak/sterk.
      buf16[i] = (int16_t)(buf32[i] >> MIC_GAIN_SHIFT);
    }

    esp_err_t res = httpd_resp_send_chunk(req, (const char*)buf16, samples * sizeof(int16_t));
    if (res != ESP_OK) {
      Serial.println("[AUDIO] Klient koblet fra");
      break;
    }
  }

  return ESP_OK;
}

// =============================================================================
// HTTP-SERVER OPPSETT
// =============================================================================
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
void loop() {
  // Alt håndteres av HTTP-server-tasks og I2S-interrupts.
  // loop() kan brukes til diagnostikk eller statusindikator senere.
  delay(10000);
}

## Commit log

2026-04-08 Initial commit: ESP32-S3 BabyMonitor with video, audio and push-to-talk
2026-04-08 Add SG90 servo pan control: /servo endpoint + arrow buttons in /player
2026-04-08 Fix servo: use ledcAttachChannel (avoid camera LEDC conflict), no PWM on boot (prevents brownout)
    [BabyMonitor.ino]
2026-04-09 Add 3D print file: camera mount enclosure (Bambu Lab .3mf, v1)
    [Kameramount_Babymonitor_v1.3mf]
2026-04-09 Add 3D print section to README with assembly notes and print settings
